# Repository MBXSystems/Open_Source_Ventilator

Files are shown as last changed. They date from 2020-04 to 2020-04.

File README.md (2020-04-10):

# UF Open Source Ventilator Project - MBX Systems Proposed Merge

Forked from the UFHealth CSSALT Lab project for an open source ventilator design, this fork contains detailed assembly documentation, clarified bill of materials, electrical schematics and updated controller code.

**Our goal is to have these contributions pulled into the core project to help accellerate public adoption of the project.**

The following updates have been made to the project and are publicly available with the intent to turn it over to the orginal UFHealth team:

* **Full assembly documentation via Dozuki** Free and open, updated project documentation hosted by Dozuki. Documentation can now be refined in a community driven manner while still maintaining the integrity of version control.
https://www.opensourceventilation.org/Guide/Open+Source+Ventilator+Assembly+(MBX+v1)/4?lang=en

* **3D assemblies** Full 3D assemblies rendered for the entire build.
-need link-

* **Clear and transparent bill of materials** Full bill of materials has been updated and refined to include additional clarity and detail on the raw material requirements.
https://docs.google.com/spreadsheets/d/1ovyo2lUL0noa83XnP0gwtcc2B9GDPE4pJonda6fv0Mo/edit?usp=sharing

* **Detailed controller schematics** 
Schematic is located here: https://upverter.com/design/mbx/b782985665a208aa/
Schematic does not include pressure controls, but it does allows for dual inline valve control which is implemented in the current code.

* **-Control Source Code Updates** -ArduinoVent Added a branch to run test without pressure sensor. Information about test program is located on test plan folder

#### Example of respirator function without controller
Respirator without controller (https://www.youtube.com/watch?v=58Gv0IUUgv8)

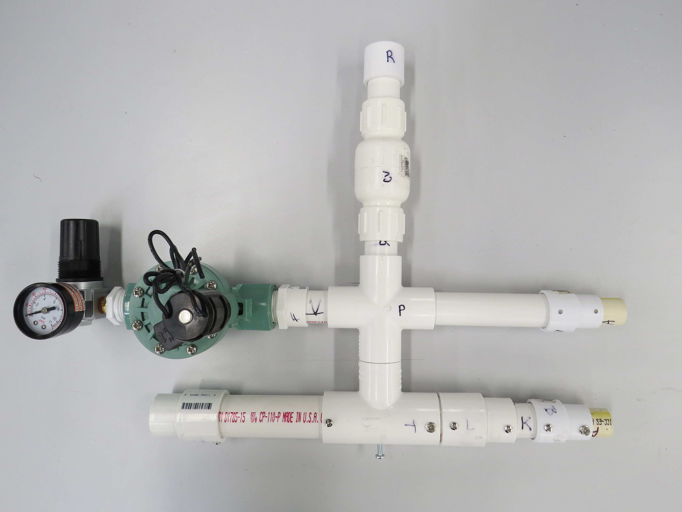
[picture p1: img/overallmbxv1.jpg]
Assembly Overview


The original project can be found here: https://simulation.health.ufl.edu/technology-development/open-source-ventilator-project/

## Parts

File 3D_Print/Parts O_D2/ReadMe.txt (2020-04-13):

Part O, and D2 were printed on a Creality CR-10 s4 (https://creality3d.shop/collections/cr-series/products/creality-cr-10-s4-3d-printer-with-filament-monitor-dual-z-axis-large-printing-size-400x400x400mm)

Using Ziro PLA (http://ziro3d.com/pla-filament/)

Designed in TinkerCAD (https://www.tinkercad.com/)

Parts were printed at a 1.2 Layer height With a .4 Nozzle. All standard print settings with a 20% Gyroid infill.200/50 for the nozzle and print bed. Brim of 5 lines. 
No supports for Part D2.
Part 0 printed with supports fromthe buld surface @15% concentric pattern.

Save Files included are .OBJ, .STL, .glb and .SVG (SVG for lasercutting)

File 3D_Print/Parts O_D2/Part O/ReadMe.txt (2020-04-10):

Part O and D2 were printed on a Creality CR-10s 

Using Ziro PLA (http://ziro3d.com/pla-filament/)

The part was designed in TinkerCAD (https://www.tinkercad.com/)

It was printed at a 1.2 Layer height with a 20% Gyroid infill, No supports, 200/50 for the nozzle and print bed Temprture. 

Save Files included for both parts are .OBJ, .STL, .glb and .SVG

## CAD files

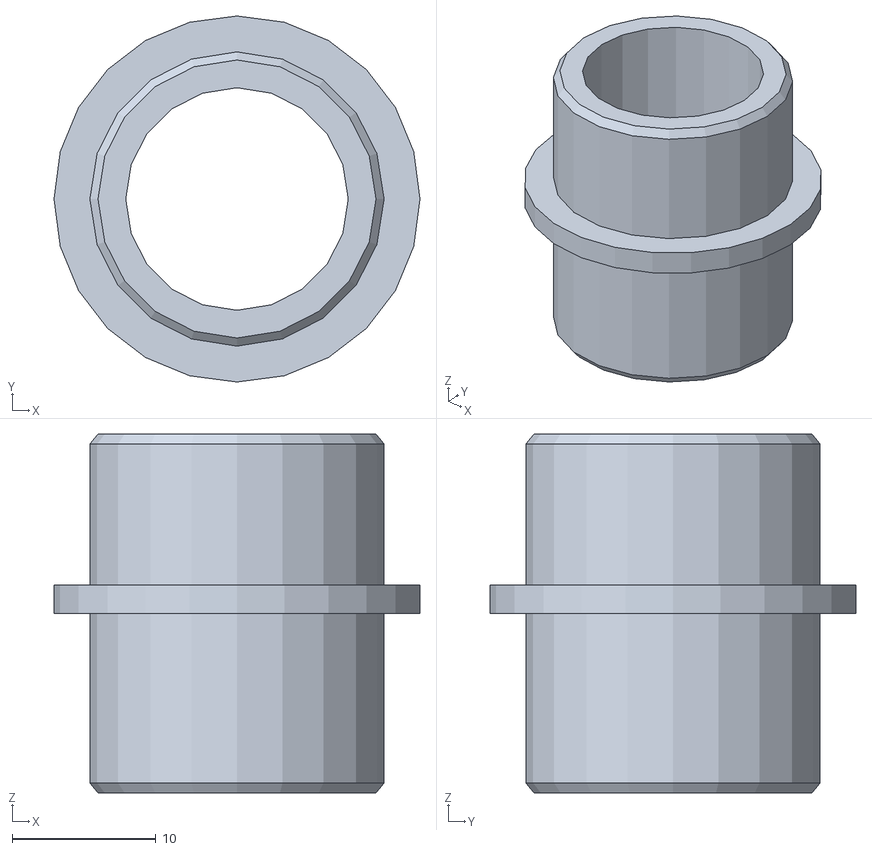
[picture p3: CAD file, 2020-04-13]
3D_Print/Parts O_D2/Part O/Part O Withoring.stl.stl
25.5 x 25.5 x 25.0

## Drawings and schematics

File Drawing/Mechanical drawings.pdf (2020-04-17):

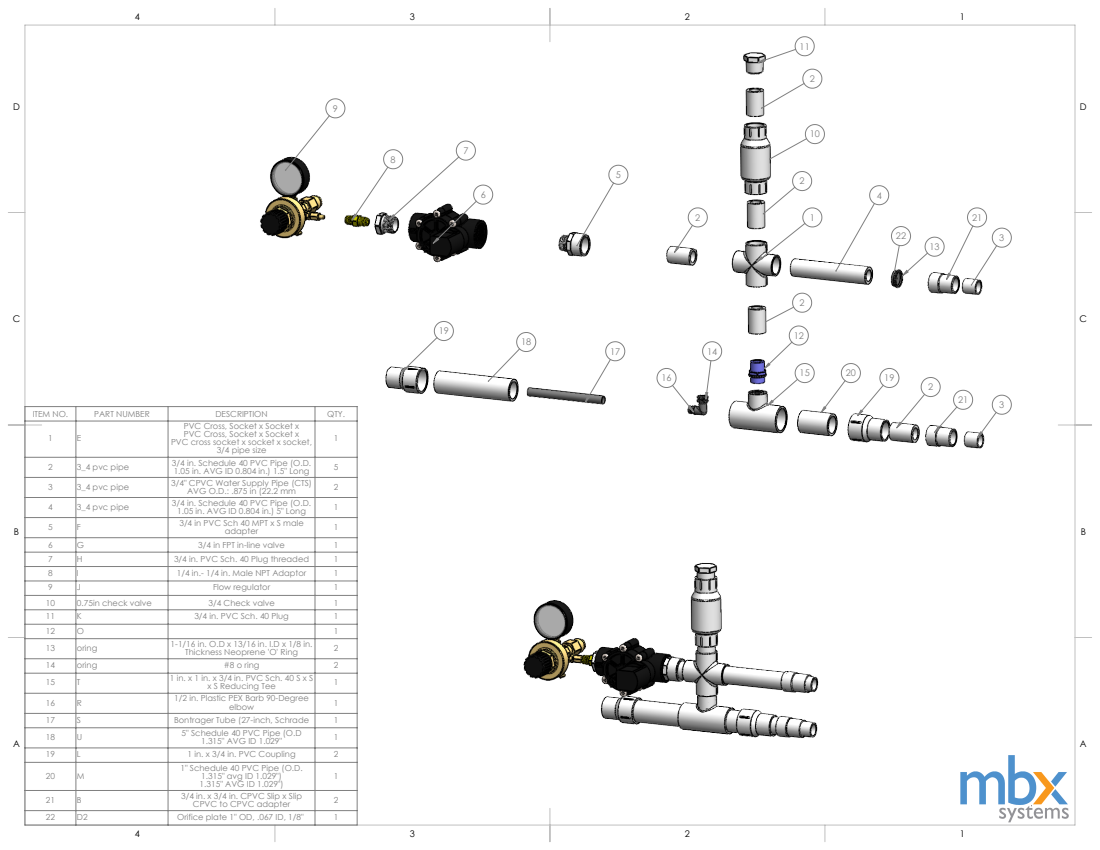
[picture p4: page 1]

ITEM NO. | E PART NUMBER | DESCRIPTION | QTY. 1

PVC Cross, Socket x Socket x PVC Cross, Socket x Socket x PVC cross socket x socket x socket, 3/4 pipe size | 1

2 | 3_4 pvc pipe | 3/4 in. Schedule 40 PVC Pipe (O.D. 1.05 in. AVG ID 0.804 in.) 1.5" Long | 5
3 | 3_4 pvc pipe | 3/4" CPVC Water Supply Pipe (CTS) AVG O.D.: .875 in (22.2 mm | 2
4 | 3_4 pvc pipe | 3/4 in. Schedule 40 PVC Pipe (O.D. 1.05 in. AVG ID 0.804 in.) 5" Long | 1
5 | F | 3/4 in PVC Sch 40 MPT x S male adapter | 1

6 | G | 3/4 in FPT in-line valve | 1
7 | H | 3/4 in. PVC Sch. 40 Plug threaded | 1
8 | I | 1/4 in.- 1/4 in. Male NPT Adaptor | 1
9 | J | Flow regulator | 1
10 | 0.75in check valve | 3/4 Check valve | 1
11 | K | 3/4 in. PVC Sch. 40 Plug | 1
12 | O | | 1
13 | oring | 1-1/16 in. O.D x 13/16 in. I.D x 1/8 in. Thickness Neoprene 'O' Ring | 2
14 | oring | #8 o ring | 2
15 | T | 1 in. x 1 in. x 3/4 in. PVC Sch. 40 S x S x S Reducing Tee | 1
16 | R | 1/2 in. Plastic PEX Barb 90-Degree elbow | 1
17 | S | Bontrager Tube (27-inch, Schrade | 1
18 | U | 5" Schedule 40 PVC Pipe (O.D 1.315" AVG ID 1.029" | 1
19 | L | 1 in. x 3/4 in. PVC Coupling | 2
20 | M | 1" Schedule 40 PVC Pipe (O.D. 1.315" avg ID 1.029") 1.315" AVG ID 1.029") | 1

21 | B | 3/4 in. x 3/4 in. CPVC Slip x Slip CPVC to CPVC adapter | 2
22 | D2 | Orifice plate 1" OD, .067 ID, 1/8" | 1

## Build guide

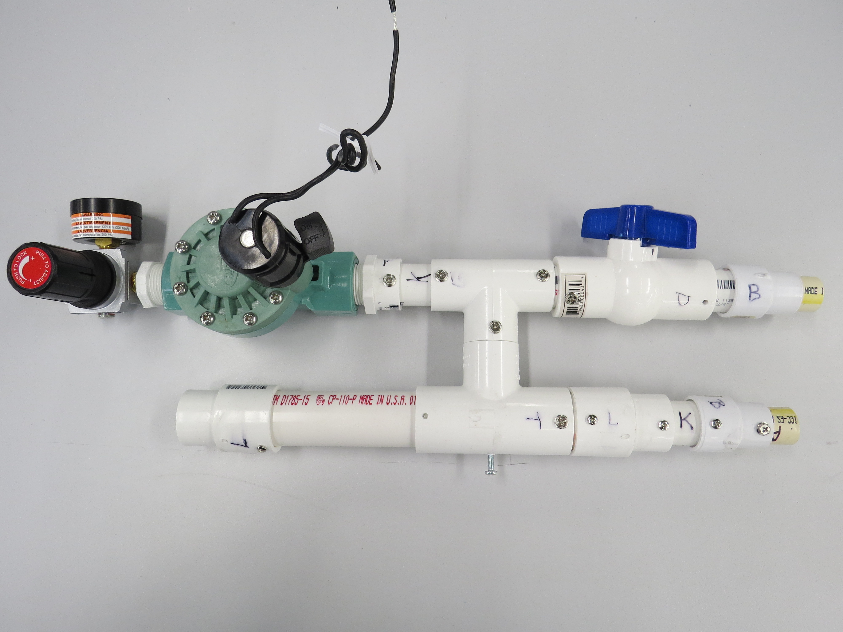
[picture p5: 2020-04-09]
img/assembly_overview.jpg

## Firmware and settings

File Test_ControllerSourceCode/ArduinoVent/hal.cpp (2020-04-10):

/*************************************************************
 * Open Ventilator
 * Copyright (C) 2020 - Marcelo Varanda
 *
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
 **************************************************************
*/


#include "hal.h"
#include "event.h"
#include "config.h"
#include "properties.h"
#include "pressure.h"


#include "EEPROM.h"



#ifdef WATCHDOG_ENABLE
  #if defined(__AVR__)
    #include <avr/wdt.h>
  #else 
    error "MPU not supported... either add support or disable watchdog."
  #endif
#endif


//---------- Constants ---------
#define EEPROM_DATA_BLOCK_ADDRESS 0

static MONITOR_LET_T monitor_led_speed = MONITOR_LED_NORMAL;

//-------- variables --------
static uint64_t tm_led;
static bool alarm = false;
static int alarm_phase = 0;
static uint64_t tm_alarm;


static uint64_t tm_key_sampling;

static char lcdBuffer [LCD_NUM_ROWS][LCD_NUM_COLS];
static int cursor_col = 0, cursor_row = 0;


static int led_state = 0;

//--------- Testing --------
static bool is_running_test_loop = false;


void toggleTestLoop()
{
  LOG("toggled test loop!");
  Serial.print("currently running?: ");
  Serial.print(is_running_test_loop);
  Serial.println("");
  is_running_test_loop = !is_running_test_loop;
  Serial.print("toggled to: ");
  Serial.print(is_running_test_loop);
  Serial.println("");
  if (is_running_test_loop){
    test_breather_event_time = halStartTimerRef(); // loop was turned on, set the event time
  }
}

bool checkTestLoopStatus()
{
  return is_running_test_loop;
}

int checkTestVentStatus()
{
  return digitalRead(VALVE_IN_PIN);
}

uint16_t getTestPotentiometerValue()
{
  return (uint16_t) analogRead(TEST_POTENTIOMETER_PIN);  //Raw analog input from test potentiometer used for rate
}

//--------- End Testing --------

#define FREQ1 440
#define FREQ2 740
#define FREQ3 880

void halBeepAlarmOnOff( bool on)
{
  if (on == true) {
    alarm = true;
    alarm_phase = 0;
    tm_alarm = halStartTimerRef();
    // turn tone on
    alarm_phase = 0;
    tone(ALARM_SOUND_PIN, FREQ1);

  }
  else {
    alarm = false;
    noTone(ALARM_SOUND_PIN);
    // turn tone off
  }
}

//----------- Locals -------------

  #ifdef LCD_CFG_I2C
    LiquidCrystal_I2C lcd(0x27,4,4);
  #else
    LiquidCrystal lcd(  LCD_CFG_RS, 
                        LCD_CFG_E, LCD_CFG_D4, 
                        LCD_CFG_D5, 
                        LCD_CFG_D6, 
                        LCD_CFG_D7);
  #endif

#define TM_WAIT_TO_ENABLE_WATCHDOG 3000

uint64_t tm_wdt = 0;
static int wdt_st;

uint64_t halStartTimerRef()
{
    static uint32_t low32, high32 = 0;
    uint32_t new_low32 = millis();
    if (new_low32 < low32) high32++;
    low32 = new_low32;
    return (uint64_t) high32 << 32 | low32;
}

bool halCheckTimerExpired(uint64_t timerRef, uint64_t time)
{
    uint64_t now = halStartTimerRef();
    if (timerRef + time < now)
        return true;
    return false;
}


static void initWdt(uint8_t reset_val)
{
#ifdef WATCHDOG_ENABLE
  wdt_st = 0;
  tm_wdt = halStartTimerRef();

  // the following line always return zero as bootloader clears the bit.
  // see hack at: https://www.reddit.com/r/arduino/comments/29kev1/a_question_about_the_mcusr_and_the_wdrf_after_a/
  //if ( MCUSR & (1<<WDRF) ) { // if we are starting dua watchdog recover LED will be fast
  if (reset_val & (1<<WDRF) ) {
    halSetMonitorLED(MONITOR_LED_FAST);
  }
  else{
    halSetMonitorLED(MONITOR_LED_NORMAL);
  }
  wdt_disable(); // keep WDT disable for a couple seconds
#else
  halSetMonitorLED(MONITOR_LED_SLOW);
#endif
}
static void loopWdt()
{
#ifdef WATCHDOG_ENABLE
  if (wdt_st == 0) { // wait to enable WDT 
    if (halCheckTimerExpired(tm_wdt, TM_WAIT_TO_ENABLE_WATCHDOG)) {
        tm_wdt = halStartTimerRef();
        wdt_st = 1;
        wdt_enable(WDTO_1S); //WDTO_2S Note: LCD Library is TOO SLOW... need to fix to get real time and lower WDT

        /* WDT possible values for ATMega 8, 168, 328, 1280, 2560
             WDTO_15MS, WDTO_30MS, WDTO_60MS, WDTO_120MS, WDTO_250MS, WDTO_500MS, WDTO_1S, WDTO_2S
           WDT possible values for  ATMega 168, 328, 1280, 2560
             WDTO_4S, WDTO_8S */
    }
    return;
  }
  //------- if we are here then WDT is enabled... kick it
  wdt_reset();
#endif
}

  
void halInit(uint8_t reset_val) {
#ifdef DEBUG_SERIAL_LOGS
  Serial.begin(9600);
  LOG("Starting...");
#endif
  pinMode(MONITOR_LED_PIN, OUTPUT);
  tm_led = halStartTimerRef();
  
  propInit();
#ifdef LCD_CFG_I2C
  lcd.init();                      // initialize the lcd 
  lcd.backlight();
#else
  #if (LCD_CFG_4_ROWS == 1)
    #if (LCD_CFG_20_COLS == 1)
        lcd.begin(20, 4);
    #else
        lcd.begin(16, 4);
    #endif
  #else
    #if (LCD_CFG_20_COLS == 1)
        lcd.begin(20, 2);
    #else
        lcd.begin(16, 2);
    #endif
  #endif
#endif
  halLcdClear();

  // -----  keys -------
  pinMode(KEY_SET_PIN, INPUT);           // set pin to input
  digitalWrite(KEY_SET_PIN, HIGH);       // turn on pullup resistors
  pinMode(KEY_INCREMENT_PIN, INPUT);           // set pin to input
  digitalWrite(KEY_INCREMENT_PIN, HIGH);       // turn on pullup resistors
  pinMode(KEY_DECREMENT_PIN, INPUT);           // set pin to input
  digitalWrite(KEY_DECREMENT_PIN, HIGH);       // turn on pullup resistors

// ------ valves -------
  pinMode(VALVE_IN_PIN, OUTPUT);           // set pin to input
  digitalWrite(VALVE_IN_PIN, HIGH);       // turn on pullup resistors
  pinMode(VALVE_OUT_PIN, OUTPUT);           // set pin to input
  digitalWrite(VALVE_OUT_PIN, HIGH);       // turn on pullup resistors
  pinMode(TEST_LOOP_BUTTON_PIN, INPUT);  
  digitalWrite(TEST_LOOP_BUTTON_PIN, LOW);
  tm_key_sampling = halStartTimerRef();
  initWdt(reset_val);
  pressInit();
}

static void testKey()
{
  #if 1
  digitalWrite(VALVE_IN_PIN, digitalRead(KEY_SET_PIN));
  #else
    digitalWrite(VALVE_IN_PIN, digitalRead(KEY_DECREMENT_PIN));
  #endif
  digitalWrite(VALVE_OUT_PIN, digitalRead(KEY_INCREMENT_PIN));
}

void halSetMonitorLED (MONITOR_LET_T speed)
{
  monitor_led_speed = speed;
}
MONITOR_LET_T halGetMonitorLED ()
{
  return monitor_led_speed;
}

void halBlinkLED()
{
  uint64_t tm;
  if (monitor_led_speed == MONITOR_LED_FAST) {
    tm = TM_MONITOR_LED_FAST;
  }
  else if (monitor_led_speed == MONITOR_LED_SLOW) {
    tm = TM_MONITOR_LED_SLOW;
  }
  else {
    tm = TM_MONITOR_LED_NORMAL;
  }
  
    if (halCheckTimerExpired(tm_led, tm)) {
        tm_led = halStartTimerRef();


        if (led_state) {
          led_state = 0;
          digitalWrite(MONITOR_LED_PIN, LOW);
        }
        else {
          led_state = 1;
          digitalWrite(MONITOR_LED_PIN, HIGH);
        }
        
    }
}
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

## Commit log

2020-04-10 Adding 3D Printed Parts within 3d_Print folder
    Part "O" and "D2"
    [Part O_STL.stl]
2020-04-13 Updated 3d printed Part "O" Design
    [Part O Withoring.stl.stl, Part O_STL.stl]
2020-04-17 Update Mechanical Drawing
    Mechanical assembly updated to match current instruction and Build of material (BOM)

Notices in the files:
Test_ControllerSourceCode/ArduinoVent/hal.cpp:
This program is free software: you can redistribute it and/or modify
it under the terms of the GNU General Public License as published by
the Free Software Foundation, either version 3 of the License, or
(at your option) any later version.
